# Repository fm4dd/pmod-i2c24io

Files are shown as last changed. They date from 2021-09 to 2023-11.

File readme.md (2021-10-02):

## PMOD-I2C24IO

 

### Description

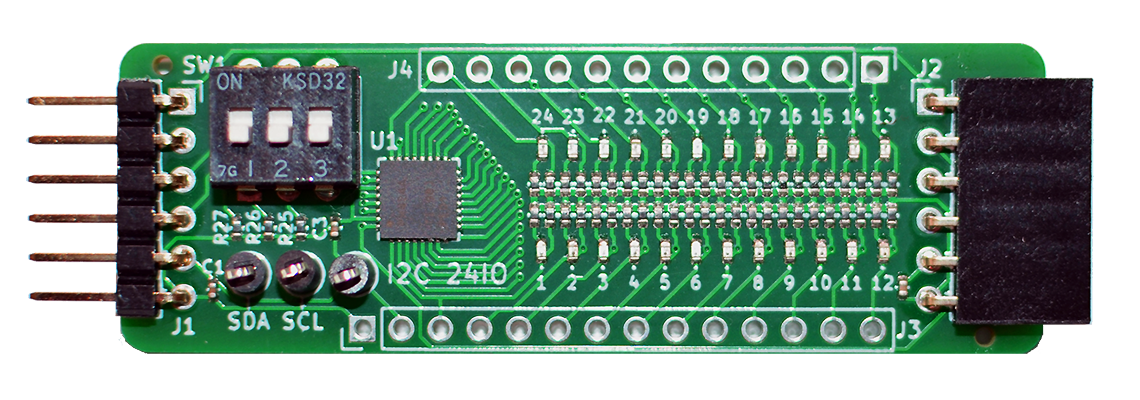
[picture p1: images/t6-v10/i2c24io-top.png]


This project is a 24-bit digital IO expander module, using the Texas Instruments TCA6424A circuit utilizing I2C. The design is available with two connector types: either Type-6 (I2C single-row) or Type-6A (I2C extended double-row) compatible interface per open PMOD interface standard v1.3.1 by Digilent Inc. PMOD (peripheral module interface) standardizes connectivity with FPGA or microcontroller development boards.
This design is registered under the OSHWA Open Source Hardware Self-Certification:  


### Function
In this module, 24 IO pins are controlled through the two-wire serial I2C protocol. For each individual IO pin, a corresponding LED displays its current status with negative logic. A pins logic level '0' lights up the LED, while level '1' turns it off. To fit all IO pins on a reasonably small PMOD, 0402-size SMD components have been selected. DIP switches enable I2C pull-up resistors if needed, and change the I2C bus address between 0x22 and 0x23. Two modules can be chained for a total of 48 IO signals. Three Testpoints can be fitted for I2C bus troubleshooting.  

See also http://fpga.fm4dd.com/

### Schematic

Type-6 v1.1 variant:

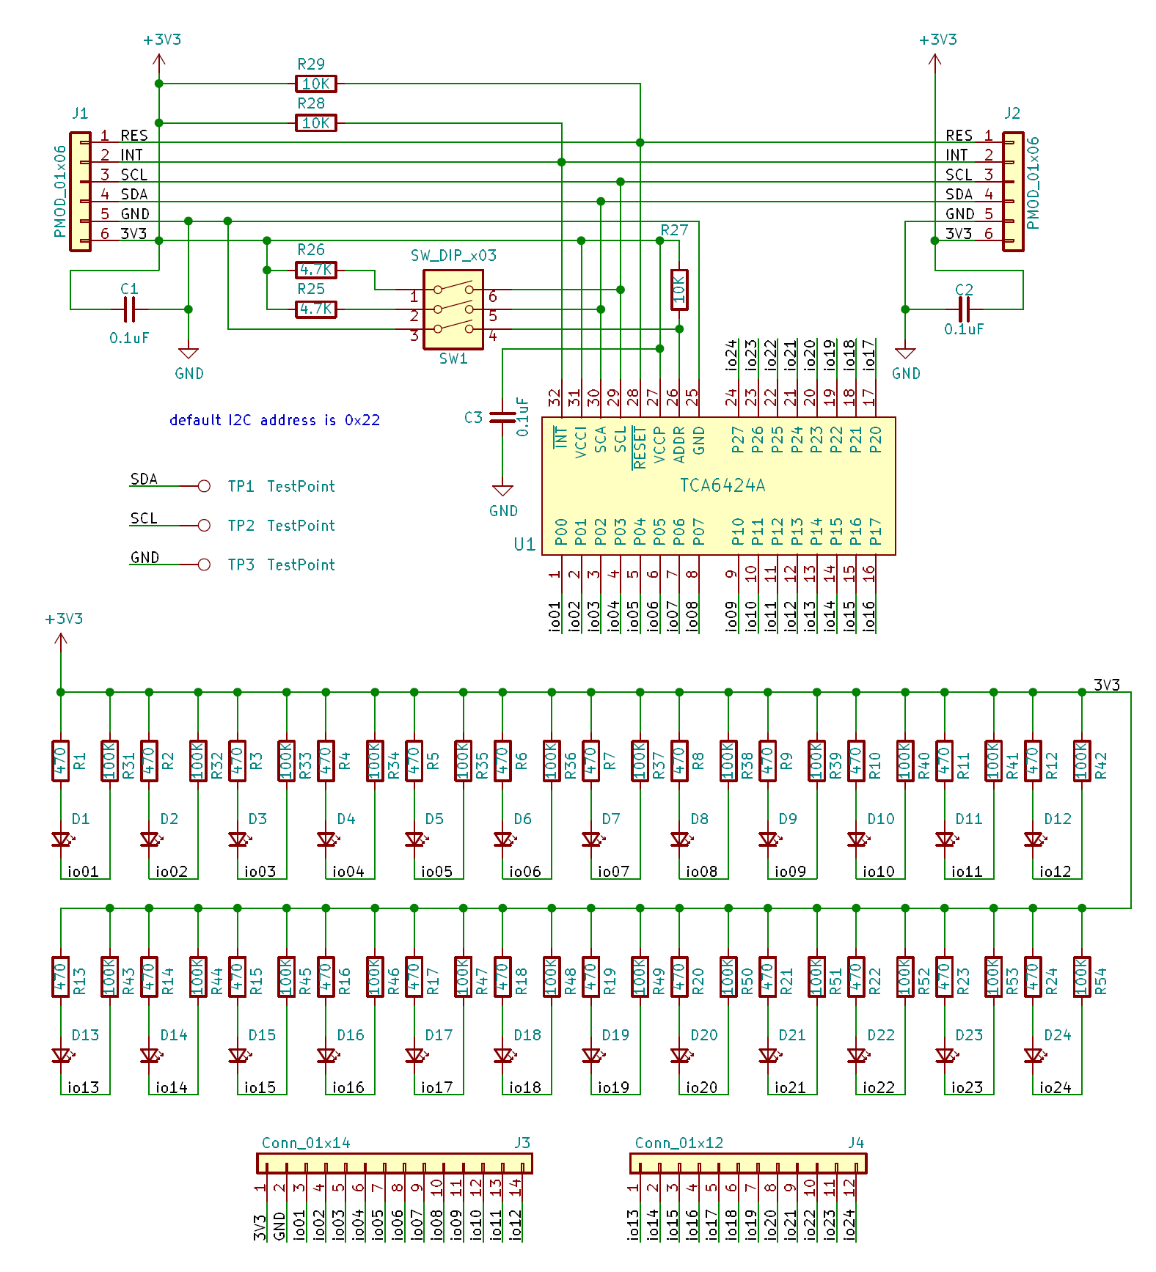
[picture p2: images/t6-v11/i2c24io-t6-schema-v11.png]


Type-6 Physical Dimensions: 60 mm x 20.3 mm

### Hardware Release

|Type | Version | Gerber | Schema |
|---|---|---|---|
|Type-6 | 1.0 |[20210906-pmod-i2c24io-t6-gerber-v10.zip](release/t6-v10/20210906-pmod-i2c24io-t6-gerber-v10.zip) | [20210906-pmod-i2c24io-t6-schema-v10.pdf](images/t6-v11/20210906-pmod-i2c24io-t6-schema-v10.pdf) |
|Type-6 |1.1 |[20210919-pmod-i2c24io-t6-gerber-v11.zip](release/t6-v11/20210919-pmod-i2c24io-t6-gerber-v11.zip) | [20210919-pmod-i2c24io-t6-schema-v11.pdf](release/t6-v11/20210919-pmod-i2c24io-t6-schema-v11.pdf)
|Type-6A  |1.1 |[20210919-pmod-i2c24io-t6a-gerber-v11.zip](release/t6a-v11/20210919-pmod-i2c24io-t6a-gerber-v11.zip) | [20210919-pmod-i2c24io-t6a-schema-v11.pdf](release/t6a-v11/20210919-pmod-i2c24io-t6a-schema-v11.pdf)

Type-6A v1.1 variant:

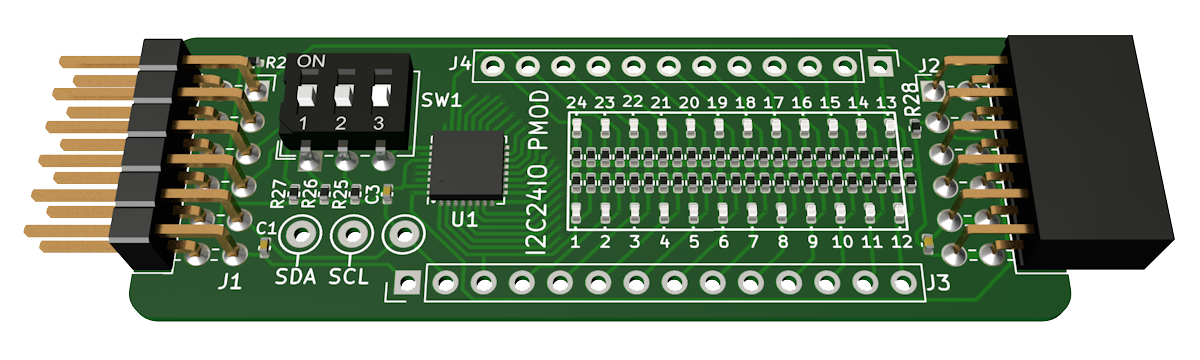
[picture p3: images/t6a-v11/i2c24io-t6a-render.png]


Type-6A Physical Dimensions: 62.5 mm x 21.7 mm

### Module Pin Assignments

Type 6:
| Pin | Signal | Description |
|-----|---|---|
| 1 | Reset  | TCA6424A Reset Pin |
| 2 | Int | TCA6424A Interrupt Pin |
| 3 | SCL | I2C Clock Signal |
| 4 | SDA | I2C Data Signal |
| 5 | GND | Power Supply Ground |
| 6 | VCC | Power Supply (3.3V) |

Type 6A (Pin 1-6 same as Type 6)

| Pin | Signal | Description |
|-----|---|---|
| 7 | IO1 | IO signal 1 |
| 8 | IO2 | IO signal 2 |
| 9 | IO3 | IO signal 3 |
| 10  | IO4 | IO signal 4 |
| 11  | GND | Power Supply Ground |
| 12  | VCC | Power Supply (3.3V) |

Note: all pin signals are passed from the module pin header to the opposite pin socket, allowing to chain another I2C module to the I2C bus.

#### Rasperry Pi I2C Discovery

First we set Reset pin 'high' to enable circuit operation by exiting the reset state. The gpioset command here is part of the 'gpiod' pin control program and library, installed with 'sudo apt install gpiod'.
```
pi@pi-ms05:~/pmod2rpi/pi-tca6424a $ gpioset gpiochip0 22=1
```
Now we can see the IO expander circuit under address 0x22 (address pin = '1'), or 0x23 (address pin = '0').
```
pi@pi-ms05:~/pmod2rpi/pi-tca6424a $ i2cdetect -y 1
     0  1  2  3  4  5  6  7  8  9  a  b  c  d  e  f
00:          -- -- -- -- -- -- -- -- -- -- -- -- --
10: -- -- -- -- -- -- -- -- -- -- -- -- -- -- -- --
20: -- -- 22 -- -- -- -- -- -- -- -- -- -- -- -- --
...
```

Note: From I2C24IO module hardware version 1.1, two additional 10K pull-up resistors (R28,29) have been fitted to auto-enable the circuit, which eliminates the need to explicitly configure the 'Reset' pin.

### Example Code

| Platform | Folder | Description |
|---|---|---|
|Raspberry Pi |[pi-tca6424a](examples/pi-tca6424a) | I2C module driver 'C' program to control the expander 24 IO output pins individually, and as a set |
|Arduino |[xiao-pmod1-i2c24io](examples/xiao-pmod1-i2c24io) | Tests I2C ports 0x22 and 0x23. If a module is found, all IO pins are set as 'output=0' (lighting up all LED) |
|Arduino |[xiao-pmod1-24iodemo](examples/xiao-pmod1-24iodemo) | Creates a lightshow demo by rotating binary patterns over the 24 IO pins, lighting up connected LEDs |

Two I2C24IO PMOD's connected to the RPi PMOD Interface board connector PMOD1 and PMOD2, running the "xiao-double-i2c24io" example program on the Seeeduino XIAO (Cortex M0):

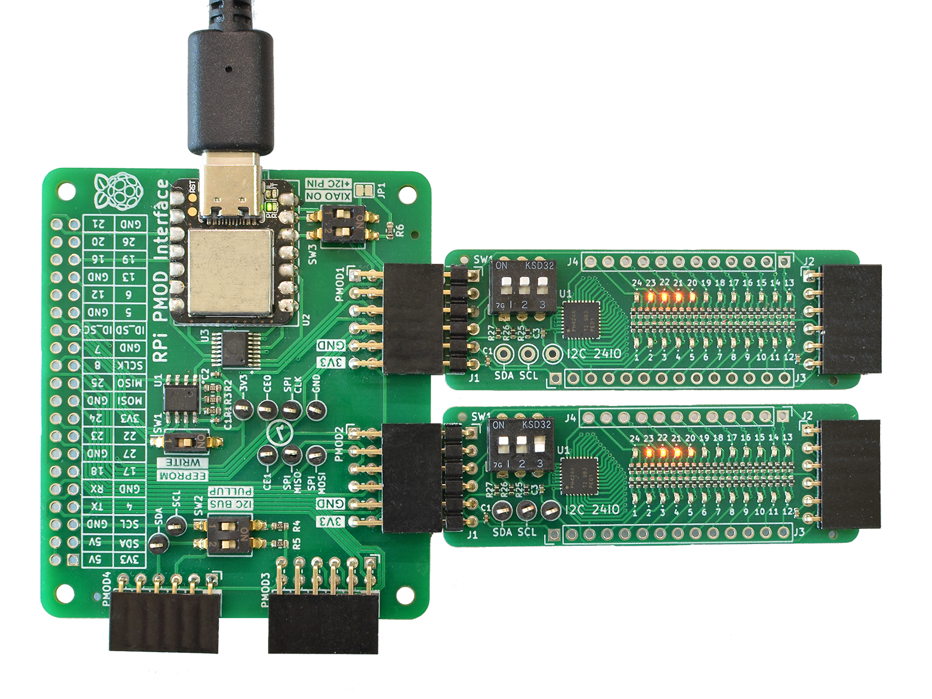
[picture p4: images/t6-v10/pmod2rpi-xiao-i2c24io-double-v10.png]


I2C24IO PMOD connected to the RPi PMOD Interface board connector PMOD4, running the "demotca6424a" example program on the Raspberry Pi:

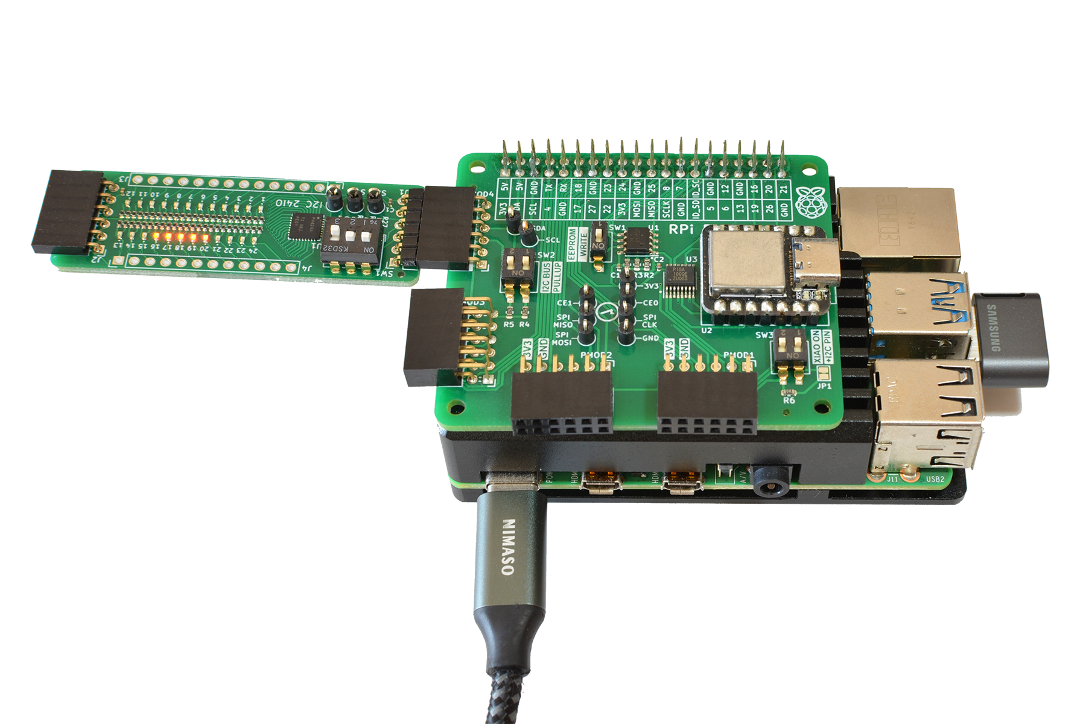
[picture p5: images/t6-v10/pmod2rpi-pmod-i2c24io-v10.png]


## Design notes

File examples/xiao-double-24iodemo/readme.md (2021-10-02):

## XIAO-DOUBLE-24IODEMO

Arduino Sketch for designs based on the I2C 24-bit digital expander IC Texas Instruments TCA6424A.
Implemented and tested on a PMOD2RPI interface board with two I2C24IO PMOD modules driven by the Seeeduino XIAO (Cortex M0+)  

### Usage

Running the sketch will output various LED patterns on both modules in parallel:

1. ON/OFF for all pins on the module
2. Moving a single bit through each of the 24 pins
3. Moving 3 bits, one for each of the 3 output ports
4. Increment pins from 0 until all port pins are ON/OFF
5. Moving 6 bits, two for each of the 3 output ports
6. Alternate the level for neighporing pins ON/OFF

Two I2C24IO PMOD's connected to the RPi PMOD Interface board connector PMOD1 and PMOD2, running the "xiao-double-i2c24io" example program on the Seeeduino XIAO (Cortex M0):



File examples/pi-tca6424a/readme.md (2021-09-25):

## Pi-TCA6424A

Linux 'C' Control Code for designs based on the I2C 24-bit digital expander IC Texas Instruments TCA6424A.
Implemented and tested on a Raspberry Pi, using the PMOD2RPI interface board and a I2C24IO PMOD module. 

### Prerequisites

```
pi@pi-ms05:~ $ sudo apt install libi2c-dev libgpiod-dev
```

### Compilation

```
pi@pi-ms05:~/pmod-i2c24io/examples/pi-tca6424a $ make
gcc -O3 -Wall -g   -c -o i2c_tca6424a.o i2c_tca6424a.c
gcc -O3 -Wall -g   -c -o settca6424a.o settca6424a.c
gcc i2c_tca6424a.o settca6424a.o -o settca6424a -lgpiod
gcc -O3 -Wall -g   -c -o demotca6424a.o demotca6424a.c
gcc i2c_tca6424a.o demotca6424a.o -o demotca6424a -lgpiod
```

### Usage
```
pi@pi-ms05:~/pmod-i2c24io/examples/pi-tca6424a $ ./settca6424a
Usage: settca6424a [-b i2c-bus] [-d] [-i] -o [<24-bit output>, or all=0/1] [-r] [-v]

Command line parameters have the following format:
   -b   I2C bus to query, Example: -b /dev/i2c-1 (default)
   -d   dump the complete sensor register map content
   -i   print sensor information
   -o   24-bit binary output string, or all=0/1 to set all pins at once
        -o 111111110000000011111111 24 x 0/1 sets individual pins
        -o all=1 sets all pins 'on', -o all=0 sets all pins 'off'
   -r   reset sensor
   -h   display this message
   -v   enable debug output

Usage examples:
./settca6424a -b /dev/i2c-0 -i
./settca6424a -o all=1
./settca6424a -o 010101010101010101010101
```

### Examples

Enable all pins as output, and set the output level as '0':
```
pi@pi-ms05:~/pmod-i2c24io/examples/pi-tca6424a $ ./settca6424a -o all=0
```
Enable all pins as output, and set the output level as '1':
```
pi@pi-ms05:~/pmod-i2c24io/examples/pi-tca6424a $ ./settca6424a -o all=1
```
Enable all pins as output, and set individual pins according to the 24-bit pattern '111111110000000010101010':
```
pi@pi-ms05:~/pmod-i2c24io/examples/pi-tca6424a $ ./settca6424a -o 111111110000000010101010 -v
Debug: ts=[1632130627] date=Mon Sep 20 18:37:07 2021
Debug: Get pin gpio22: [direction 2]
Debug: Get pin gpio22: [act_state 1]
Debug: Set pin gpio22: [output '1']
Debug: I2C bus device: [/dev/i2c-1]
Debug: Sensor address: [0x22]
Debug: Got data @addr: [0x22]
Debug: Setting all ports as output complete
Debug: port0 data str: [11111111] hex [0xFF]
Debug: port1 data str: [00000000] hex [0x00]
Debug: port2 data str: [10101010] hex [0xAA]
Debug: Setting pin output as [111111110000000010101010] complete
```
Small one-liner to set pins as output, and alternate the pins output level:
``` 
pi@pi-ms05:~/pmod-i2c24io/examples/pi-tca6424a $ while true; do ./settca6424a -o 101010101010101010101010; \
> sleep 0.5; ./settca6424a -o 010101010101010101010101; sleep 0.5; done
```
Set a specific pin value, and dump the TCA6424A register values:
```
pi@pi-ms05:~/pmod-i2c24io/examples/pi-tca6424a $ ./settca6424a -o 111111110000000010101010
pi@pi-ms05:~/pmod-i2c24io/examples/pi-tca6424a $ ./settca6424a -d
------------------------------------------------------
Texas Instruments TCA6424A register dump:
------------------------------------------------------
 reg    0  1  2  3  4  5  6  7  8  9  A  B  C  D  E  F
------------------------------------------------------
[0x00] FF 00 AA -- FF 00 AA -- 00 00 00 -- 00 00 00 --
```

### Demo

```
pi@pi-ms05:~/pmod-i2c24io/examples/pi-tca6424a $ ./demotca6424a
```

demotca6424 is demonstration program for designs based on the I2C 24-bit digital expander IC Texas Instruments TCA6424A.
Implemented and tested on a Raspberry Pi 4 with a PMOD2RPI interface board, having the I2C24IO PMOD module on the PMOD4 connector.

### Usage

```
pi@pi-ms05:~/pmod-i2c24io/examples/pi-tca6424a $ ./demotca6424a -h
Usage: demotca6424a [-a addr] [-b i2c-bus] [-v]

Command line parameters have the following format:
   -a   module I2C bus address in hex, Example: -a 0x22 (default)
   -b   I2C bus to query, Example: -b /dev/i2c-1 (default)
   -h   display this message
   -v   enable debug output

Usage examples:
./demotca6424a -a 0x23 -b /dev/i2c-0
./demotca6424a -v
```

Running the sketch will output various LED patterns that indicate the IO signal status:

1. ON/OFF for all pins on the module
2. Moving a single bit through each of the 24 pins
3. Moving 3 bits, one for each of the 3 output ports
4. Increment pins from 0 until all port pins are ON/OFF
5. Moving 6 bits, two for each of the 3 output ports
6. Alternate the level for neighporing pins ON/OFF

This program executes in a permanent loop, terminate the program with 'CTL-C'.

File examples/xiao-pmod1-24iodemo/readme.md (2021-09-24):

## XIAO-PMOD1-24IODEMO

Arduino Sketch for designs based on the I2C 24-bit digital expander IC Texas Instruments TCA6424A.
Implemented and tested on a PMOD2RPI interface board with a Seeeduino XIAO (Cortex M0+) and a I2C24IO PMOD module. 

### Usage

Running the sketch will output various LED patterns that indicate the IO signal status:

1. ON/OFF for all pins on the module
2. Moving a single bit through each of the 24 pins
3. Moving 3 bits, one for each of the 3 output ports
4. Increment pins from 0 until all port pins are ON/OFF
5. Moving 6 bits, two for each of the 3 output ports
6. Alternate the level for neighporing pins ON/OFF

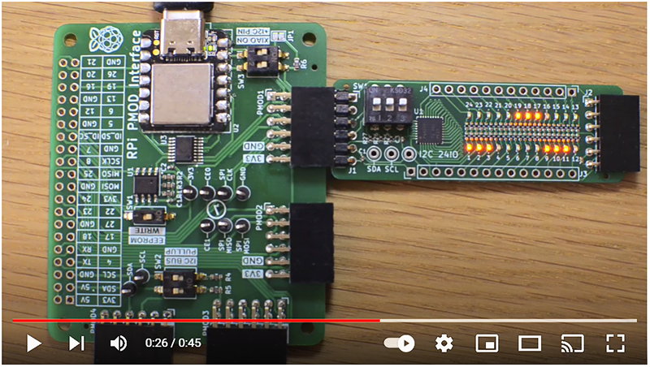
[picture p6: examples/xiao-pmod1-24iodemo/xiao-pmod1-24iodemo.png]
Watch the video (https://www.youtube.com/watch?v=qveKCJ2Uwl0)


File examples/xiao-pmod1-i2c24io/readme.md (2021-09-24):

## XIAO-PMOD1-I2C24IO

Arduino Sketch for designs based on the I2C 24-bit digital expander IC Texas Instruments TCA6424A.
Implemented and tested on a PMOD2RPI interface board with a Seeeduino XIAO (Cortex M0+) and a I2C24IO PMOD module. 

### Usage

Running the sketch will output the following to the serial monitor:

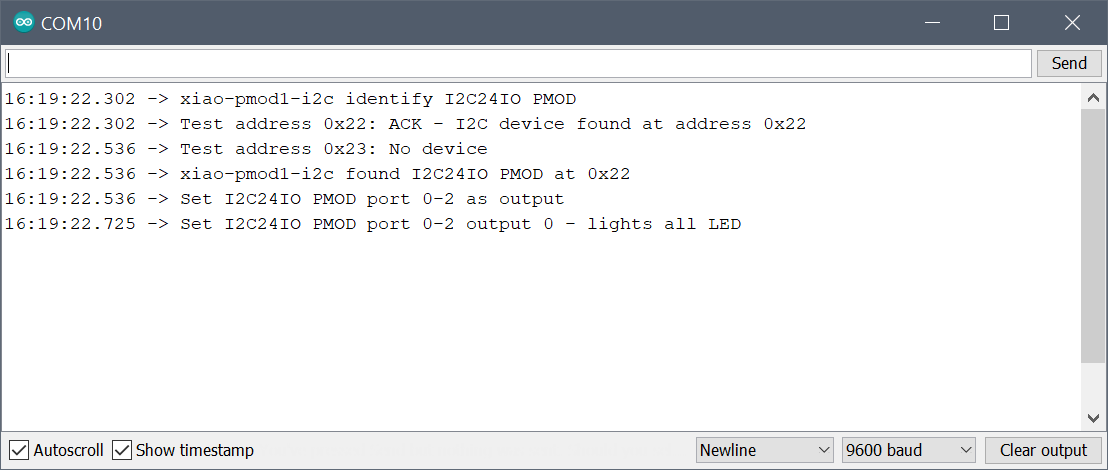
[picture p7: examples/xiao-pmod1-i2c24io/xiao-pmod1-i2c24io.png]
Sketch output to serial monitor


PMOD2RPI interface board with a Seeeduino XIAO (Cortex M0+) and a I2C24IO PMOD module:

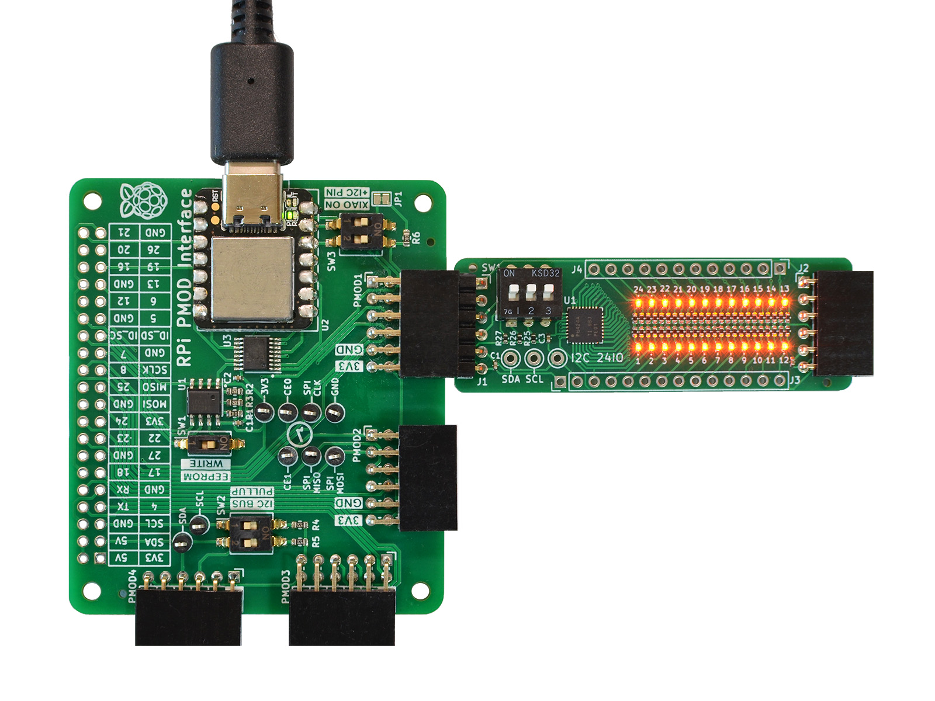
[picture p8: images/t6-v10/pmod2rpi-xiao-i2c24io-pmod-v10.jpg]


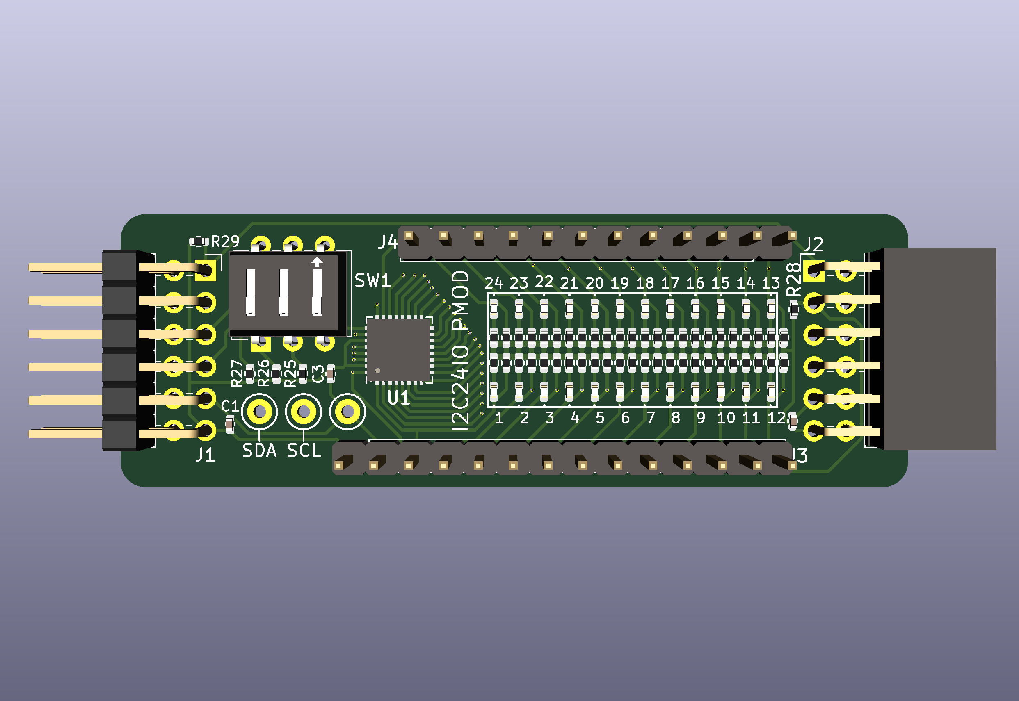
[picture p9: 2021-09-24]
images/t6a-v11/i2c24io-front.png

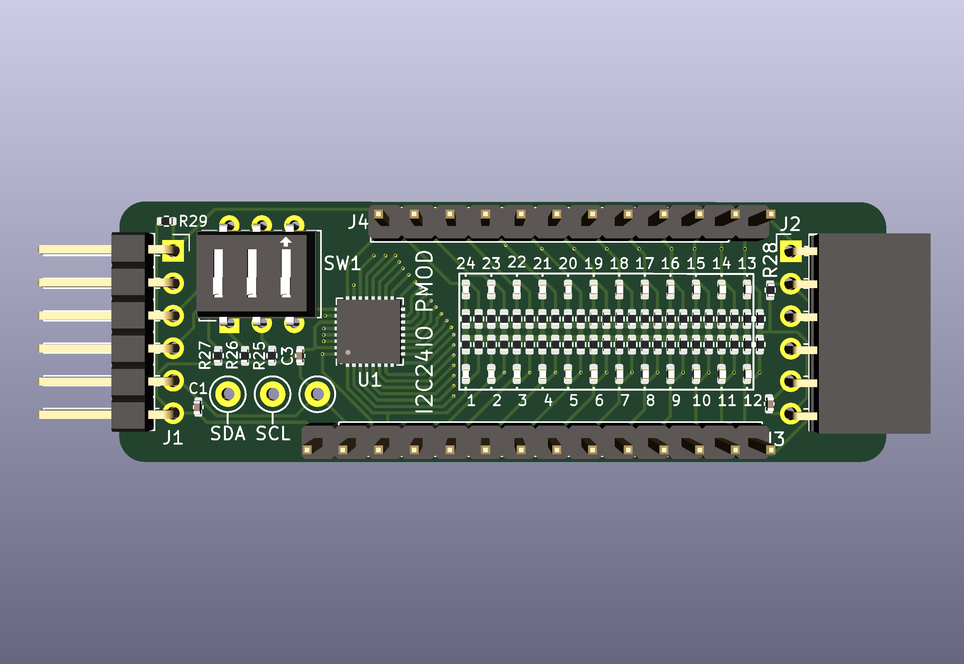
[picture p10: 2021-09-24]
images/t6-v11/i2c24io-front.png

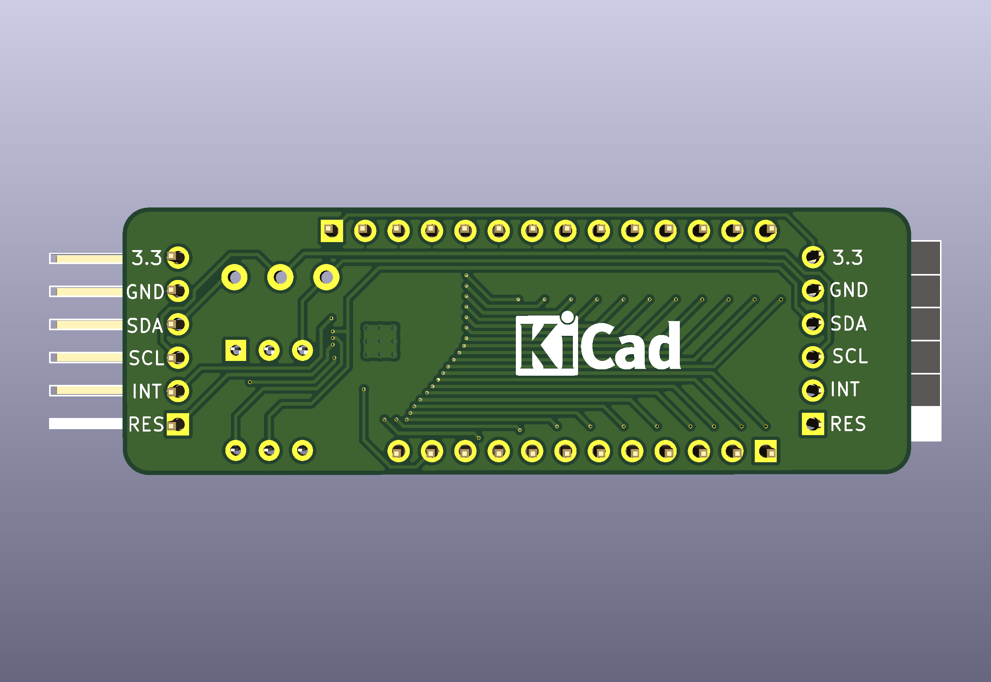
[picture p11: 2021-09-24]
images/t6-v11/i2c24io-back.png

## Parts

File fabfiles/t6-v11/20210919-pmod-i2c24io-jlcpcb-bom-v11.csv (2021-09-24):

Comment | Designator | Package | LCSC Part
0402WGF4700TCE | R24,R23,R22,R21,R20,R19,R18,R17,R16,R15,R14,R13,R12,R11,R10,R9,R8,R7,R6,R5,R4,R3,R2,R1 | Resistor_SMD:R_0402_1005Metric | C25117
TCA6424ARGJR | U1 | UQFN-32-1EP_5x5mm_ThermalVias | C80692
TJ-S1005SW4TGLC0A-A5 | D24,D23,D22,D21,D20,D19,D18,D17,D16,D15,D14,D13,D12,D11,D10,D9,D8,D7,D6,D5,D4,D3,D2,D1 | LED_SMD:LED_0402_1005Metric | C273599
C0402C104K4RECAUTO | C3,C2,C1 | Capacitor_SMD:C_0402_1005Metric | C696352
0402WGF1002TCE | R27,R28,R29 | Resistor_SMD:R_0402_1005Metric | C25744
0402WGF4701TCE | R26,R25 | Resistor_SMD:R_0402_1005Metric | C25900
0402WGF1003TCE | R54,R44,R53,R52,R51,R50,R49,R48,R47,R46,R45,R43,R41,R40,R39,R38,R37,R36,R35,R34,R33,R32,R31,R42 | Resistor_SMD:R_0402_1005Metric | C25741

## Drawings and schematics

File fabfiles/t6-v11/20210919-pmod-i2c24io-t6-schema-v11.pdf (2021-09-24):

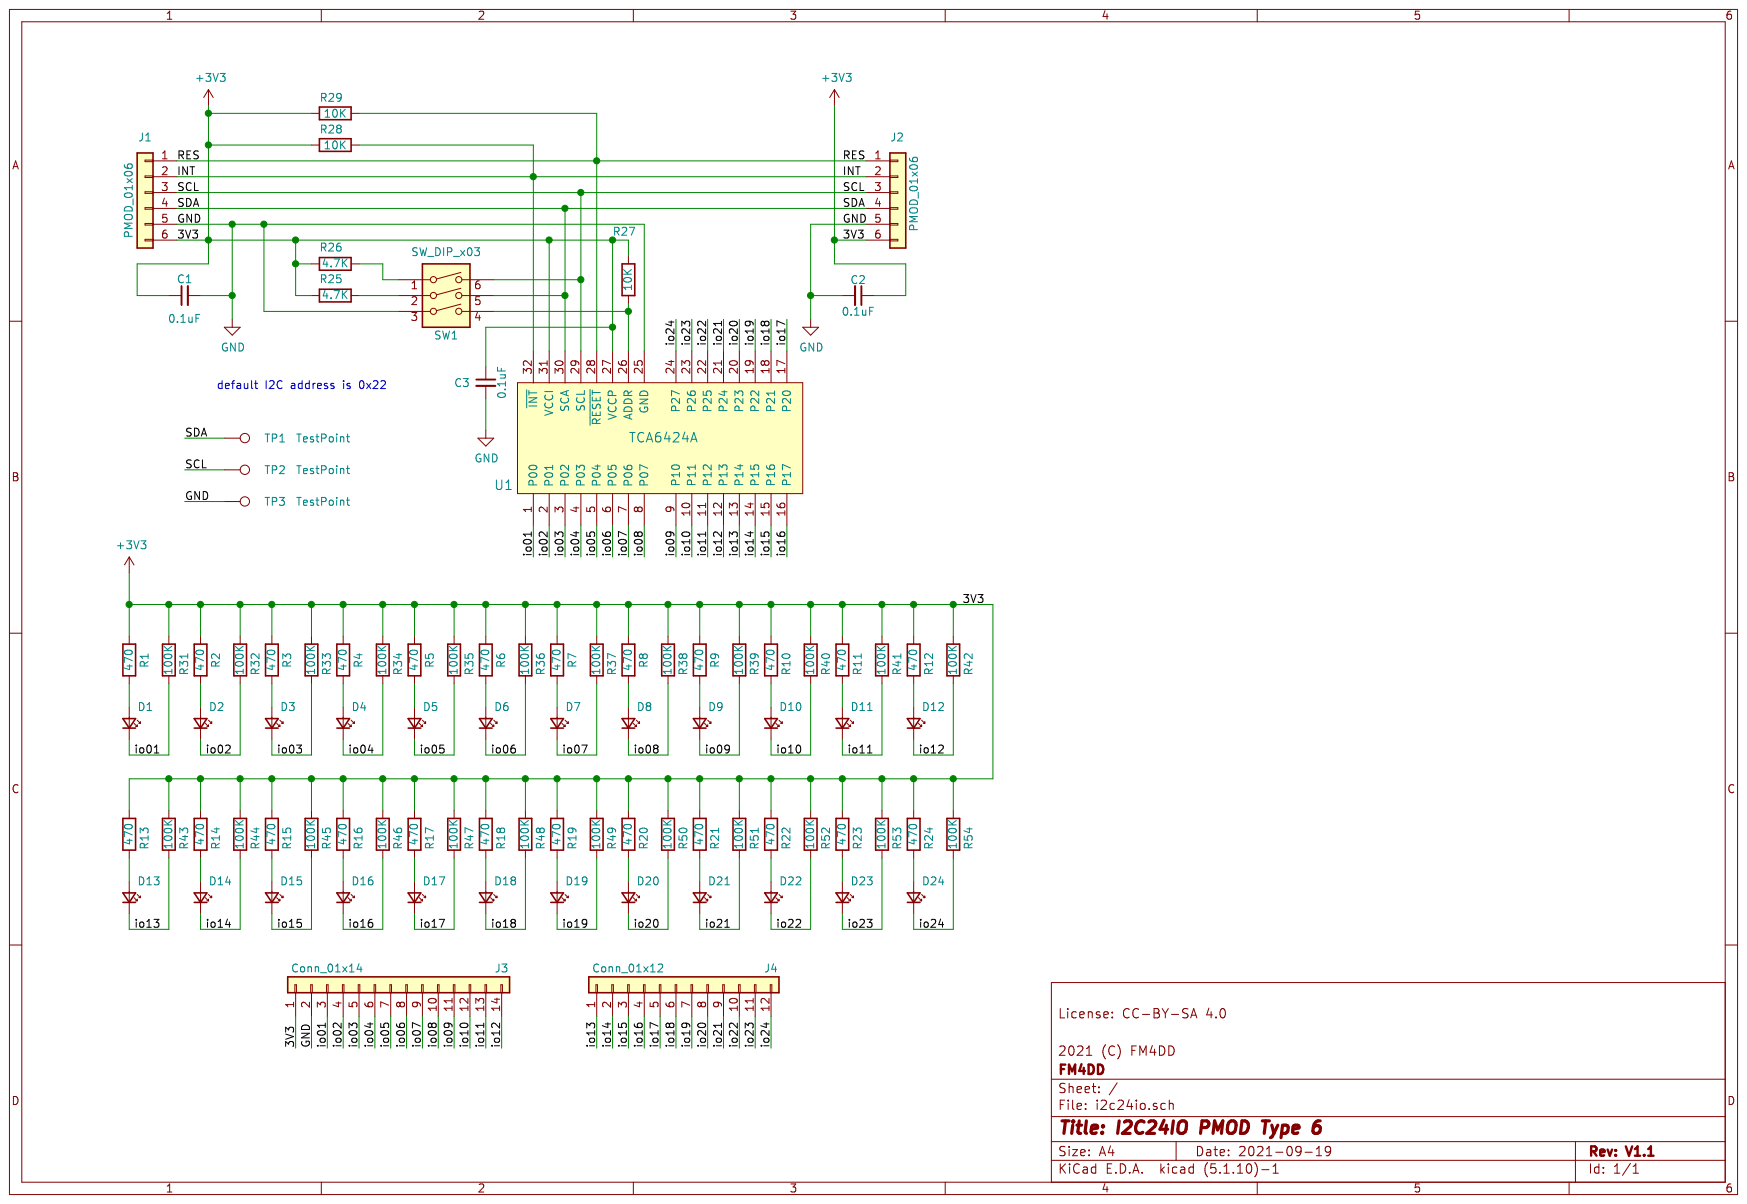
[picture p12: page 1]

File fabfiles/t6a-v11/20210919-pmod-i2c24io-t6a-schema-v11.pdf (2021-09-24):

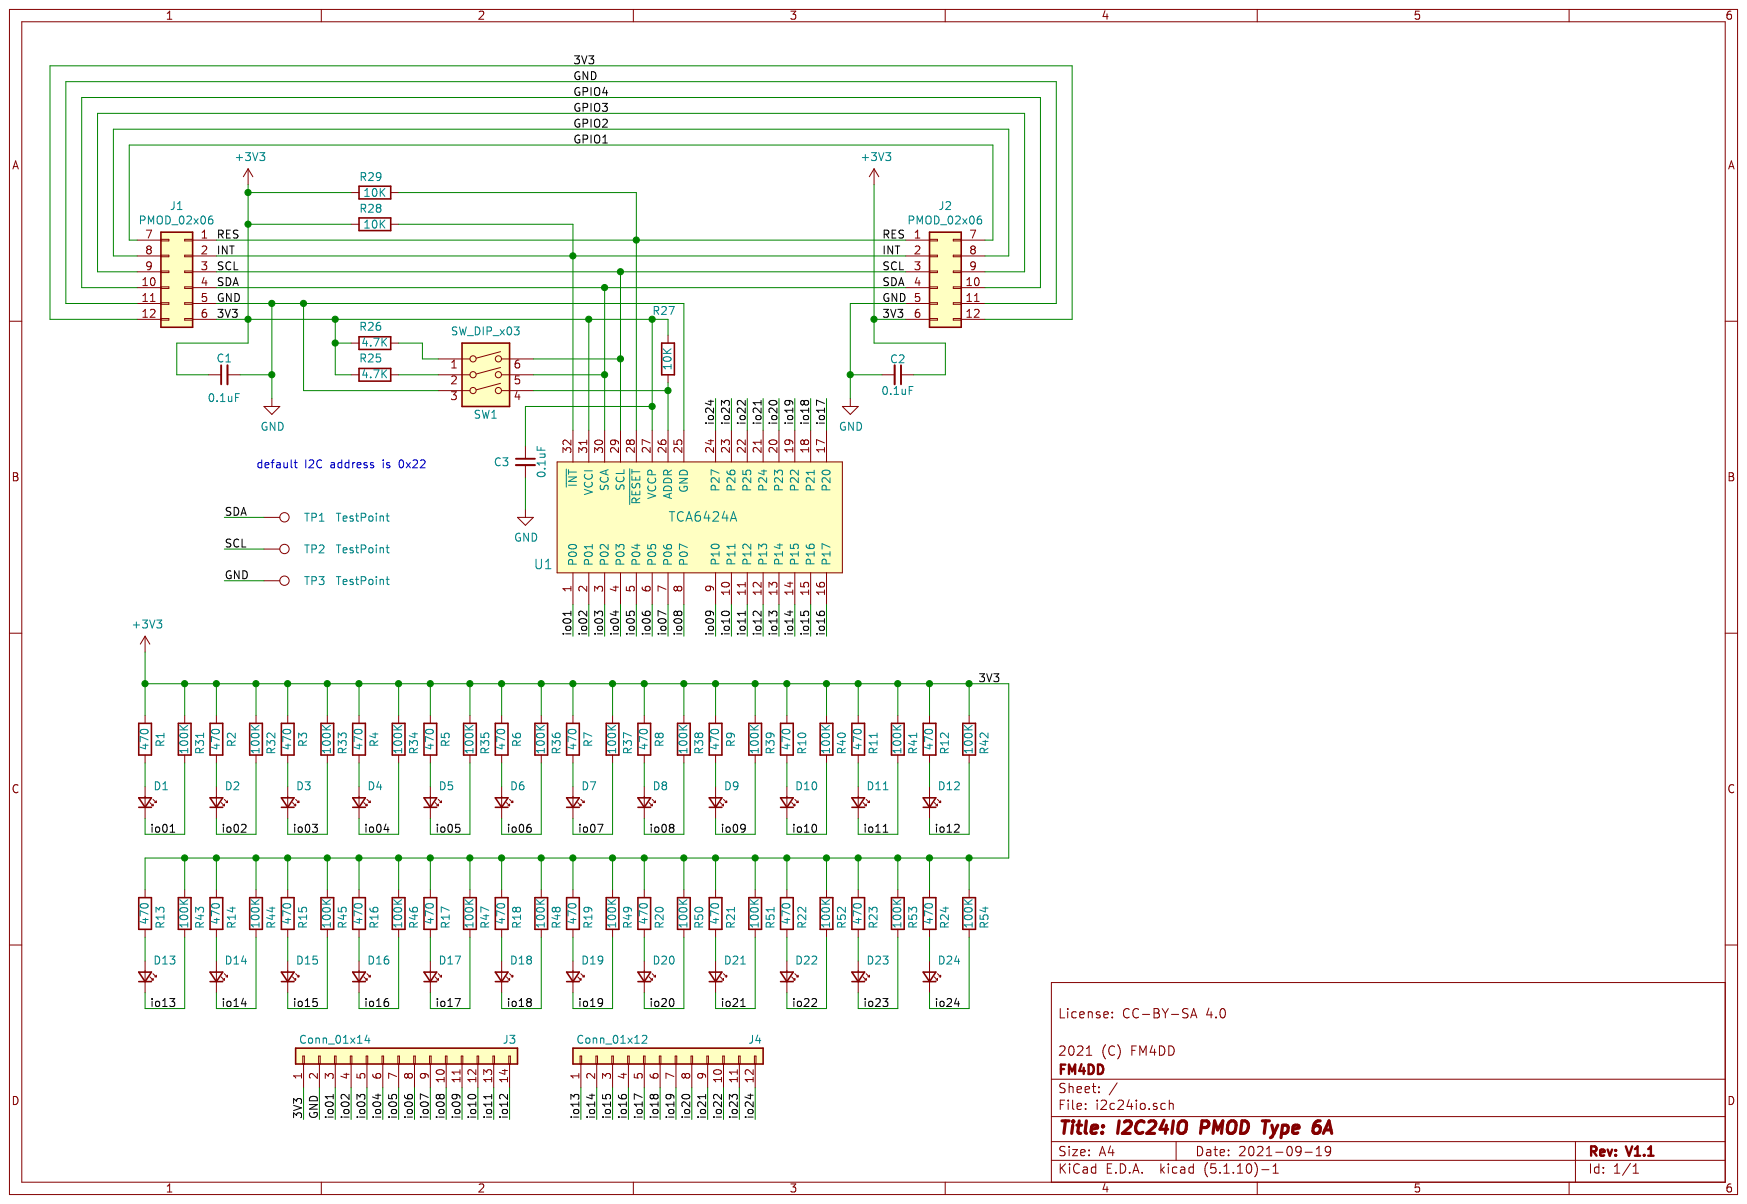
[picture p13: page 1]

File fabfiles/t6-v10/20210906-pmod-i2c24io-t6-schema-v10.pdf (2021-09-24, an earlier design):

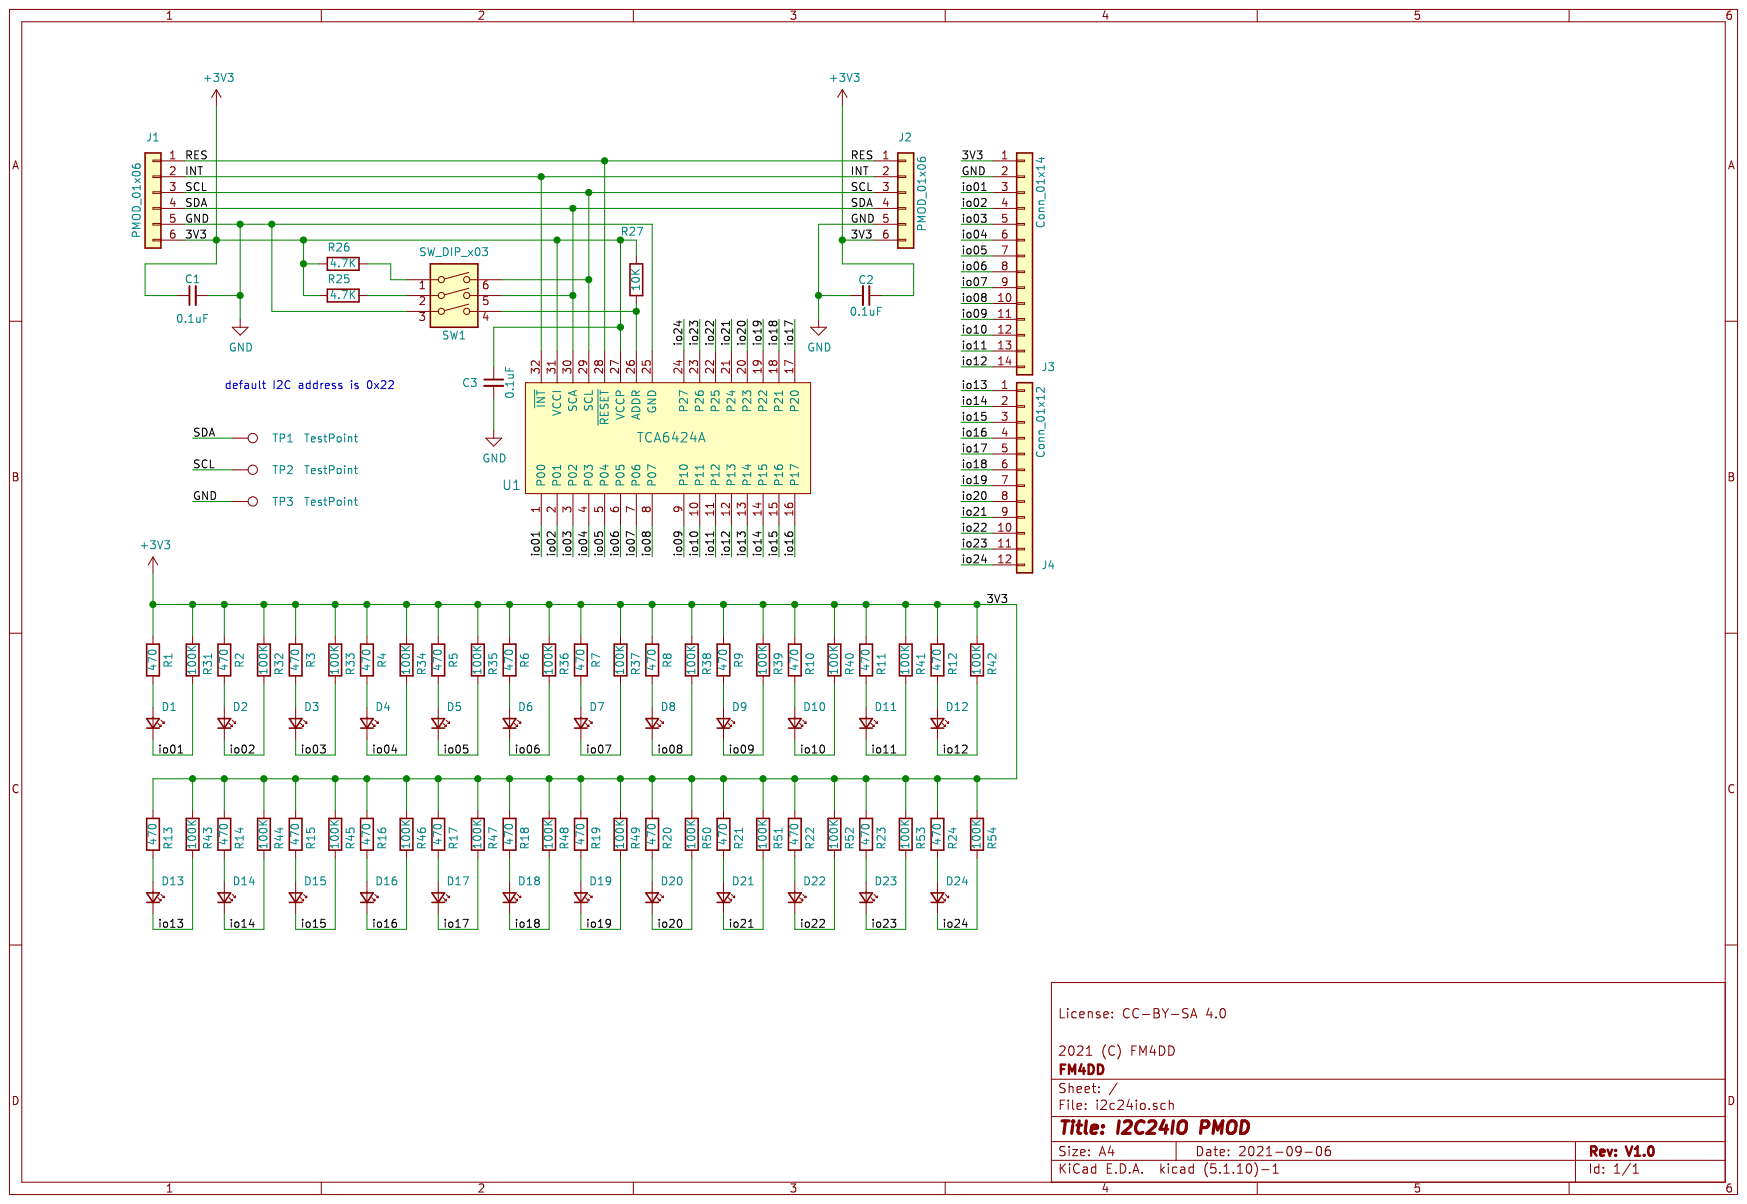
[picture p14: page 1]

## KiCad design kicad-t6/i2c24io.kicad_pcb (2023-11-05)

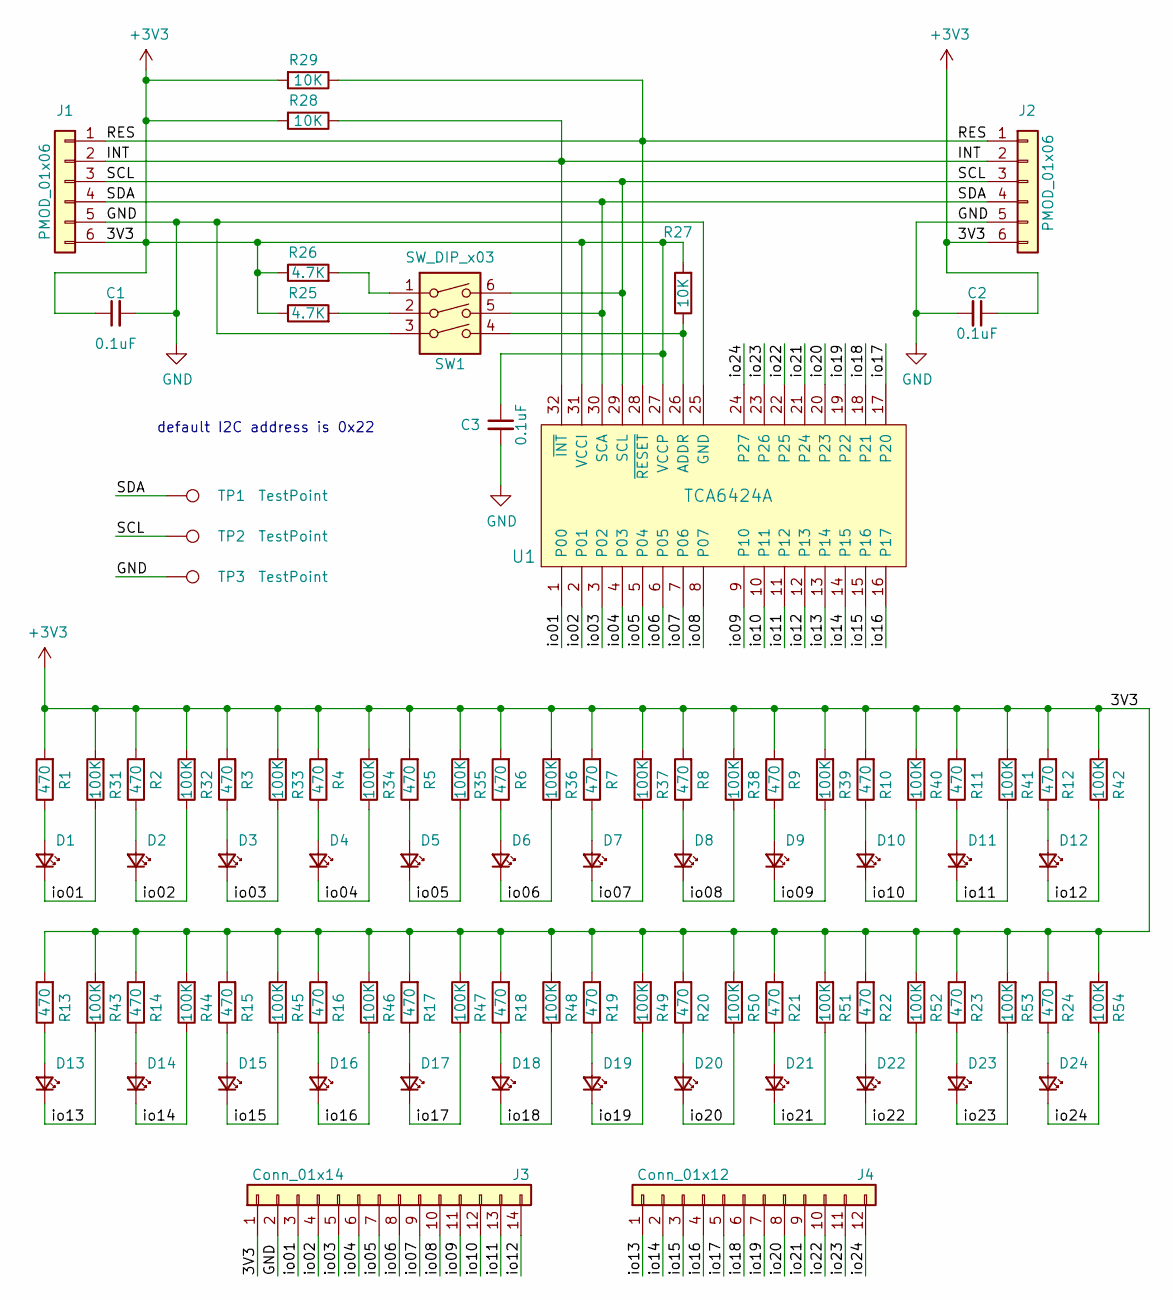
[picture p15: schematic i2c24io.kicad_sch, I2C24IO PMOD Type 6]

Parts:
C1, C2, C3: 0.1uF; C_0402_1005Metric
D1, D2, D3, D4, D5, D6, D7, D8, D9, D10, D11, D12, D13, D14, D15, D16, D17, D18, D19, D20, D21, D22, D23, D24: LED_Small; LED_0402_1005Metric
J1: PMOD_01x06; PMOD_Header_1x06_P2.54mm_Horizontal
J2: PMOD_01x06; PMODPinSocket_1x06_P2.54mm_Horizontal
J3: Conn_01x14; PinHeader_1x14_P2.54mm_Vertical
J4: Conn_01x12; PinHeader_1x12_P2.54mm_Vertical
R1, R2, R3, R4, R5, R6, R7, R8, R9, R10, R11, R12, R13, R14, R15, R16, R17, R18, R19, R20, R21, R22, R23, R24: 470; R_0402_1005Metric
R25, R26: 4.7K; R_0402_1005Metric
R27, R28, R29: 10K; R_0402_1005Metric
R31, R32, R33, R34, R35, R36, R37, R38, R39, R40, R41, R42, R43, R44, R45, R46, R47, R48, R49, R50, R51, R52, R53, R54: 100K; R_0402_1005Metric
SW1: SW_DIP_x03; SW_DIP_SPSTx03_Slide_6.7x9.18mm_W7.62mm_P2.54mm_LowProfile
TP1, TP2, TP3: TestPoint; TestPoint_Keystone_5000-5004_Miniature
U1: TCA6424A; VQFN-32-1EP_5x5mm_P0.5mm_EP3.1x3.1mm_ThermalVias

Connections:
+3V3: C1.1, C2.1, C3.1, J1.6, J2.6, J3.1, R1.2, R2.2, R3.2, R4.2, R5.2, R6.2, R7.2, R8.2, R9.2, R10.2, R11.2, R12.2, R13.2, R14.2, R15.2, R16.2, R17.2, R18.2, R19.2, R20.2, R21.2, R22.2, R23.2, R24.2, R25.1, R26.1, R27.2, R28.2, R29.2, R31.2, R32.2, R33.2, R34.2, R35.2, R36.2, R37.2, R38.2, R39.2, R40.2, R41.2, R42.2, R43.2, R44.2, R45.2, R46.2, R47.2, R48.2, R49.2, R50.2, R51.2, R52.2, R53.2, R54.2, U1.27 (VCCP), U1.31 (VCCI)
/INT: J1.2, J2.2, R28.1, U1.32 (~INT)
/RES: J1.1, J2.1, R29.1, U1.28 (~RESET)
/SCL: J1.3, J2.3, SW1.6, TP2.1, U1.29 (SCL)
/SDA: J1.4, J2.4, SW1.5, TP1.1, U1.30 (SCA)
/io01: D1.1 (K), J3.3, R31.1, U1.1 (P00)
/io02: D2.1 (K), J3.4, R32.1, U1.2 (P01)
/io03: D3.1 (K), J3.5, R33.1, U1.3 (P02)
/io04: D4.1 (K), J3.6, R34.1, U1.4 (P03)
/io05: D5.1 (K), J3.7, R35.1, U1.5 (P04)
/io06: D6.1 (K), J3.8, R36.1, U1.6 (P05)
/io07: D7.1 (K), J3.9, R37.1, U1.7 (P06)
/io08: D8.1 (K), J3.10, R38.1, U1.8 (P07)
/io09: D9.1 (K), J3.11, R39.1, U1.9 (P10)
/io10: D10.1 (K), J3.12, R40.1, U1.10 (P11)
/io11: D11.1 (K), J3.13, R41.1, U1.11 (P12)
/io12: D12.1 (K), J3.14, R42.1, U1.12 (P13)
/io13: D13.1 (K), J4.1, R43.1, U1.13 (P14)
/io14: D14.1 (K), J4.2, R44.1, U1.14 (P15)
/io15: D15.1 (K), J4.3, R45.1, U1.15 (P16)
/io16: D16.1 (K), J4.4, R46.1, U1.16 (P17)
/io17: D17.1 (K), J4.5, R47.1, U1.17 (P20)
/io18: D18.1 (K), J4.6, R48.1, U1.18 (P21)
/io19: D19.1 (K), J4.7, R49.1, U1.19 (P22)
/io20: D20.1 (K), J4.8, R50.1, U1.20 (P23)
/io21: D21.1 (K), J4.9, R51.1, U1.21 (P24)
/io22: D22.1 (K), J4.10, R52.1, U1.22 (P25)
/io23: D23.1 (K), J4.11, R53.1, U1.23 (P26)
/io24: D24.1 (K), J4.12, R54.1, U1.24 (P27)
GND: C1.2, C2.2, C3.2, J1.5, J2.5, J3.2, SW1.3, TP3.1, U1.25 (GND)
unnamed: D1.2 (A), R1.1
unnamed: D2.2 (A), R2.1
unnamed: D3.2 (A), R3.1
unnamed: D4.2 (A), R4.1
unnamed: D5.2 (A), R5.1
unnamed: D6.2 (A), R6.1
unnamed: D7.2 (A), R7.1
unnamed: D8.2 (A), R8.1
unnamed: D9.2 (A), R9.1
unnamed: D10.2 (A), R10.1
unnamed: D11.2 (A), R11.1
unnamed: D12.2 (A), R12.1
unnamed: D13.2 (A), R13.1
unnamed: D14.2 (A), R14.1
unnamed: D15.2 (A), R15.1
unnamed: D16.2 (A), R16.1
unnamed: D17.2 (A), R17.1
unnamed: D18.2 (A), R18.1
unnamed: D19.2 (A), R19.1
unnamed: D20.2 (A), R20.1
unnamed: D21.2 (A), R21.1
unnamed: D22.2 (A), R22.1
unnamed: D23.2 (A), R23.1
unnamed: D24.2 (A), R24.1
unnamed: R25.2, SW1.2
unnamed: R26.2, SW1.1
unnamed: R27.1, SW1.4, U1.26 (ADDR)

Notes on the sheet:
default I2C address is 0x22

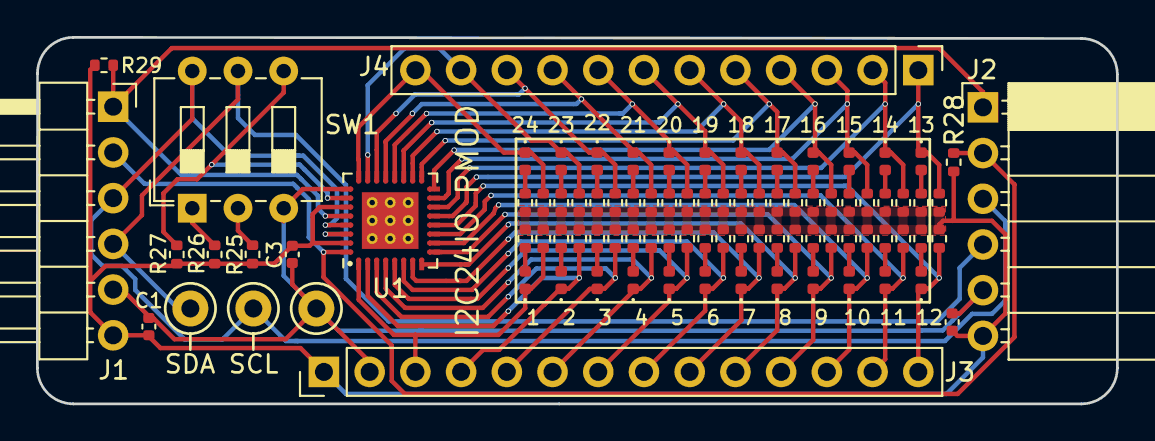
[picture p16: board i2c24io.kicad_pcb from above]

Board: 2 copper layers, 60.0 x 20.4 mm, 89 parts (0 on the bottom side), 57 nets.

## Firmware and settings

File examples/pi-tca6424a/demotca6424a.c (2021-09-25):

/* ------------------------------------------------------------ *
 * file:        demotca6424a.c                                  *
 * purpose:     Demo program for the 24-IO I2C TCA6426A port    *
 *              expander module I2C24IO PMOD on a Raspberry Pi  *
 *                                                              *
 * return:      0 on success, and -1 on errors.                 *
 *                                                              *
 * requires:	I2C library headers and GPIOD library           *
 *              e.g. sudo apt install libi2c-dev libgpiod-dev   *
 *                                                              *
 * compile:	gcc -o demotca6424a i2c_tca6424a.c \            *
 *              demotca6424a.c                                  *
 *                                                              *
 * author:      09/25/2021 Frank4DD                             *
 * ------------------------------------------------------------ */
#include <stdlib.h>
#include <stdio.h>
#include <stdint.h>
#include <ctype.h>
#include <unistd.h>
#include <string.h>
#include <getopt.h>
#include <time.h>
#include "tca6424a.h"

/* ------------------------------------------------------------ *
 * Global variables and defaults                                *
 * ------------------------------------------------------------ */
int verbose = 0;
int outflag = 0;
int argflag = 0;             // 1=dump, 2=info, 3=reset, 4=set
char i2c_bus[256] = I2CBUS;  // set I2C bus default value for RPi
char i2caddr[256] = I2CADDR; // set default I2C address as 0x22
char outset[25] = "";        // output signal argument string

/* ------------------------------------------------------------ *
 * print_usage() prints the programs commandline instructions.  *
 * ------------------------------------------------------------ */
void usage() {
   static char const usage[] = "Usage: demotca6424a [-a addr] [-b i2c-bus] [-v]\n\
\n\
Command line parameters have the following format:\n\
   -a   module I2C bus address in hex, Example: -a 0x22 (default)\n\
   -b   I2C bus to query, Example: -b /dev/i2c-1 (default)\n\
   -h   display this message\n\
   -v   enable debug output\n\
\n\
\n\
Usage examples:\n\
./demotca6424a -a 0x23 -b /dev/i2c-0\n\
./demotca6424a -v\n\\n";
   printf(usage);
}

/* ------------------------------------------------------------ *
 * parseargs() checks the commandline arguments with C getopt   *
 * ------------------------------------------------------------ */
void parseargs(int argc, char* argv[]) {
   int arg;
   opterr = 0;

//   if(argc == 1) { usage(); exit(-1); }

   while ((arg = (int) getopt (argc, argv, "a:b:hv")) != -1) {
      switch (arg) {
         // arg -a + I2C address, type: string, example "0x23"
         case 'a':
            if(verbose == 1) printf("Debug: arg -a, value %s\n", optarg);
            if (strlen(optarg) != 4 || optarg[0] != '0' || optarg[1] != 'x') {
               printf("Error: Cannot get valid -a I2C address argument.\n");
               exit(-1);
            }
            strncpy(i2caddr, optarg, sizeof(i2caddr));
            break;

         // arg -b + I2C bus device name, type: string, example: "/dev/i2c-1"
         case 'b':
            if(verbose == 1) printf("Debug: arg -b, value %s\n", optarg);
            if (strlen(optarg) >= sizeof(i2c_bus)) {
               printf("Error: I2C bus argument to long.\n");
               exit(-1);
            }
            strncpy(i2c_bus, optarg, sizeof(i2c_bus));
            break;

         // arg -h usage, type: flag, optional
         case 'h':
            usage(); exit(0);
            break;

         // arg -v verbose
         case 'v':
            verbose = 1; break;

         case '?':
            if(isprint (optopt))
               printf ("Error: Unknown option `-%c'.\n", optopt);
            else
               printf ("Error: Unknown option character `\\x%x'.\n", optopt);
            usage();
            exit(-1);
            break;

         default:
            usage();
            break;
      }
   }
}

/* ------------------------------------------------------- */
/* Single LED walkthrough - 1..24 Runs single LED light    */
/* around the circle.                                      */
/* ------------------------------------------------------- */
void move1(char mode, int millisec) {
  char out_data;
  
  if(mode) tca6424a_setall(1);            // all LEDs off
  else tca6424a_setall(0);                // all LEDs on
  for(char i=0; i<8; i++) {               // cycle port bits
    out_data = 0x01 << i;                 // 0x01 = 00000001
    if(mode) out_data = ~out_data;        // send port data
    writePort(0, out_data);               // write data to port
    delay(millisec);                      // change speed
  }
  // Delete the last LED before moving on
  if(mode)out_data = 0xFF;                // all port LED off
  else out_data = 0x00;                   // all port LED on
  writePort(0, out_data);

  for(char i=0; i<8; i++) {               // cycle port bits
    out_data = 1 << i;
    if(mode) out_data = ~out_data;        // send port data
    writePort(1, out_data);               // write data to port
    delay(millisec);                      // change speed
  }
  // Delete the last LED before moving on
  if(mode)out_data = 0xFF;                // all port LED off
  else out_data = 0x00;                   // all port LED on
  writePort(1, out_data);

  for(char i=0; i<8; i++) {               // cycle port bits
    out_data = 1 << i;
    if(mode) out_data = ~out_data;        // send port data
    writePort(2, out_data);               // write data to port
    delay(millisec);                      // change speed
  }
  // Delete the last LED before moving on
  if(mode)out_data = 0xFF;                // all port LED off
  else out_data = 0x00;                   // all port LED on
  writePort(2, out_data);
}

/* ------------------------------------------------------- */
/* Single LED walkthrough - 1..8 Runs single LED light     */
/* in each port. Looks as if 3 lights move in a circle.    */
/* ------------------------------------------------------- */
void move1in8(char mode, int millisec) {
  char out_data;
  
  if(mode) tca6424a_setall(1);            // all LEDs off
  else tca6424a_setall(0);                // all LEDs on
  for(char i=0; i<8; i++) {               // cycle port bits
    out_data = 0x01 << i;                 // 0x01 = 00000001
    if(mode) out_data = ~out_data;        // send port data
    writePort(0, out_data);               // write data to port
    writePort(1, out_data);               // write data to port
    writePort(2, out_data);               // write data to port
    delay(millisec);                      // change speed
  }
  // Delete the last LED before moving on
  if(mode)out_data = 0xFF;                // all port LED off
  else out_data = 0x00;                   // all port LED on
  writePort(0, out_data);
  writePort(1, out_data);
  writePort(2, out_data);
}

/* ------------------------------------------------------- */
/* Increment Pattern LED1 - LED12 - LED123 ..LED12345678   */
/* in each port.                                           */
/* ------------------------------------------------------- */
void incr1in8(char mode, int millisec) {
  char out_data, data = 0x00;

  if(mode) tca6424a_setall(1);             // all LEDs off
  else tca6424a_setall(0);                 // all LEDs on
  for(char i=0; i<8; i++) {                // cycle port bits
    data = data | 0x01 << i;
    if(mode) out_data = ~data;
    else out_data = data;
    writePort(0, out_data);               // write data to port
    writePort(1, out_data);               // write data to port
    writePort(2, out_data);               // write data to port
    delay(millisec);                      // change speed
  }
  // Reset all before moving on
  if(mode)out_data = 0xFF;                // all port LED off
  else out_data = 0x00;                   // all port LED on
  writePort(0, out_data);
  writePort(1, out_data);
  writePort(2, out_data);
}

/* ------------------------------------------------------- */
/* Single LED walkthrough - 1..4 Runs two LED lights       */
/* in each port. Looks as if 6 lights move in a circle.    */
/* ------------------------------------------------------- */
void move1in4(char mode, int millisec) {
  char out_data;
  
  if(mode) tca6424a_setall(1);            // all LEDs off
  else tca6424a_setall(0);                // all LEDs on
  for(char i=0; i<4; i++) {               // cycle port bits
    out_data = 0x11 << i;                 // 0x11 = 00010001
    if(mode) out_data = ~out_data;        // send port data
    writePort(0, out_data);               // write data to port
    writePort(1, out_data);               // write data to port
    writePort(2, out_data);               // write data to port
    delay(millisec);                      // change speed
  }
  // Delete the last LED before moving on
  if(mode)out_data = 0xFF;                // all port LED off
  else out_data = 0x00;                   // all port LED on
  writePort(0, out_data);
  writePort(1, out_data);
  writePort(2, out_data);
}

/* ------------------------------------------------------- */
/* alternate() Switch on every second LED on the expander  */
/* and alternate the LED with it's neighbor LED.           */
/* ------------------------------------------------------- */
void alternate(int millisec) {
  char out_data = 0xAA;
  writePort(0, out_data);
  writePort(1, out_data);
  writePort(2, out_data);
  delay(millisec);
  out_data = 0x55;
  writePort(0, out_data);
  writePort(1, out_data);
  writePort(2, out_data);
  delay(millisec); 
}

int main(int argc, char *argv[]) {
   int i = 0;

   /* ---------------------------------------------------------- *
    * Process the cmdline parameters                             *
    * ---------------------------------------------------------- */
   parseargs(argc, argv);

   /* ----------------------------------------------------------- *
    * get current time (now), output at program start if verbose  *
    * ----------------------------------------------------------- */
   time_t tsnow = time(NULL);
   if(verbose == 1) printf("Debug: ts=[%lld] date=%s", (long long) tsnow, ctime(&tsnow));

   /* ----------------------------------------------------------- *
    * Open the I2C bus connecting to the i2c address 0x22 or 0x23 *
    * ----------------------------------------------------------- */
   get_i2cbus(i2c_bus, i2caddr);

   /* ----------------------------------------------------------- *
    *   Run the demo in a forever loop                            *
    * ----------------------------------------------------------- */
   tca6424a_allout();
   while(1) {
      tca6424a_setall(0);
      delay(500);
      tca6424a_setall(1);
      delay(500);
      tca6424a_setall(0);
      delay(500);
      tca6424a_setall(1);
      delay(500);
      for(i=0; i<6; i++) move1(1, 50);
      for(i=0; i<5; i++) move1(0, 50);
      for(i=0; i<16; i++) move1in8(1, 50);
      for(i=0; i<6; i++)  move1in8(0, 50);
      for(i=0; i<4; i++) { 
         incr1in8(1, 50);
         incr1in8(0, 50);
      }
      for(i=0; i<24; i++) move1in4(1, 50);
      for(i=0; i<10; i++) move1in4(0, 50);
      for(i=0; i<10; i++) alternate(200);
      delay(500);
   }
   exit(0);
}

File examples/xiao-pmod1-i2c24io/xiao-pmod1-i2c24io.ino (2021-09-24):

// --------------------------------------
// xiao-pmod1-i2c
//
// A modified i2c-scanner.ino program to test
// the TI TCA6424A-based I2C24IO PMOD connected
// to a PMOD2RPI PMOD interface board's PMOD1
//
// This sketch tests for response on the I2C
// device address 0x22 and 0x23
//
// I2C24IO PMOD connected to PMOD1 lower row
// I2C24IO PMOD SW1 ON/ON/ON = PullUp + 0x22
// PMOD1 XIAO I2C pin assignment SW3 ON/ON
// -----------------------------------------
// pmod1-1 = XIAO gpio D7  / pin J4-1 = RESET
// pmod1-2 = XIAO gpio D10 / pin J4-4 = INT
// pmod1-3 = XIAO gpio D9  / pin J4-3 = SCL
// pmod1-4 = XIAO gpio D8  / pin J4-2 = SDA
//
// I2C24IO PMOD connected to PMOD1 upper row
// PMOD1 XIAO I2C pin assignment SW3 ON/OFF
// -----------------------------------------
// pmod1-5 = XIAO gpio D3  / pin J2-4 = LD4
// pmod1-6 = XIAO gpio D2  / pin J2-3 = LD5
// pmod1-7 = XIAO gpio D5  / pin J2-6 = LD6
// pmod1-8 = XIAO gpio D4  / pin J2-5 = LD7
// -----------------------------------------
// Note:
// PMOD2RPI SW3 flips pmod1-3/4 with pmod1-7/8 

#include <Wire.h>
byte addr1 = 0x22;
byte addr2 = 0x23;
byte addr = 0x0;

void setup() {
  Wire.begin();
  Serial.begin(9600);
  while (!Serial) {} // wait for serial port to connect. Needed for native USB port only
  Serial.println("xiao-pmod1-i2c identify I2C24IO PMOD");
  byte error;
  pinMode(7, OUTPUT);
  pinMode(10, OUTPUT);
  pinMode(8, OUTPUT);
  pinMode(3, OUTPUT);
  digitalWrite( 7, HIGH); // RESET lower row
  digitalWrite(10, HIGH); // INT lower row
  digitalWrite( 8, HIGH); // RESET upper row
  digitalWrite( 3, HIGH); // INT upper row
  
  Serial.print("Test address 0x22: ");
  Wire.beginTransmission(addr1);
  error = Wire.endTransmission();
  if (error == 0){
    Serial.println("ACK - I2C device found at address 0x22");
    addr = addr1;
  }
  else if (error==4) {
    Serial.println("Unknown error at address 0x22");
  }
  else Serial.println("No device");
  delay(200);
  Serial.print("Test address 0x23: ");
  Wire.beginTransmission(addr2);
  error = Wire.endTransmission();
  if (error == 0){
    Serial.println("ACK - I2C device found at address 0x23");
    addr = addr2;
  }
  else if (error==4) {
    Serial.println("Unknown error at address 0x23");
  }
  else Serial.println("No device");
  if (addr == 0x0) {
    Serial.println("No device found, exiting program...");
    exit(0);
  }
  Serial.print("xiao-pmod1-i2c found I2C24IO PMOD at 0x");
  Serial.print(addr, HEX);
  Serial.println();
  Serial.println("Set I2C24IO PMOD port 0-2 as output");
  byte port0_conf_reg = 0x8c;   // use the auto-increment register addr
  byte port_conf_data = 0x00;   // switch default 0xFF input to 0x00 output
  Wire.beginTransmission(addr); // start data sending
  Wire.write(port0_conf_reg);   // send address of port0 config register
  Wire.write(port_conf_data);   // send 0x00 to config port0 as output
  Wire.write(port_conf_data);   // send 0x00 to config port1 as output
  Wire.write(port_conf_data);   // send 0x00 to config port2 as output
  Wire.endTransmission();       // stop transmitting
  delay(200);
  Serial.println("Set I2C24IO PMOD port 0-2 output 0 - lights all LED");
  byte port0_out_reg = 0x84;    // use the auto-increment register addr
  byte port_out_data = 0x00;    // send 0x00 since LED light at 0-signal
  Wire.beginTransmission(addr); // start data sending
  Wire.write(port0_out_reg);    // send address of port0 output register
  Wire.write(port_out_data);    // send 0x00 to set port0 output 00000000
  Wire.write(port_out_data);    // send 0x00 to set port0 output 00000000
  Wire.write(port_out_data);    // send 0x00 to set port0 output 00000000
  Wire.endTransmission();       // stop transmitting
}
void loop(){}

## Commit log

2021-09-24 initial check in
    [20210821-pmod-i2c24io-jlcpcb-bom-v10.csv, 20210919-pmod-i2c24io-jlcpcb-bom-v11.csv, 20210919-pmod-i2c24io-t6a-bom-v11.csv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]
2023-11-05 KiCad v7 upgrade and GCC v10 fix
    [i2c24io.kicad_pcb, i2c24io.kicad_sch, i2c24io.sch]

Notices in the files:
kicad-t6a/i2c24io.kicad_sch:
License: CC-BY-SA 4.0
